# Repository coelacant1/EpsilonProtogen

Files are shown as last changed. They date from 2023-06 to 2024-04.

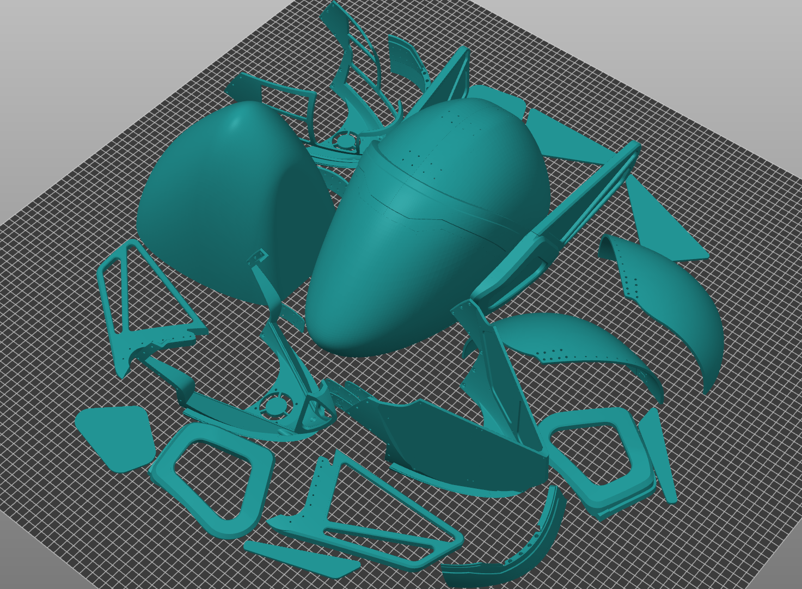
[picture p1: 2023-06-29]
Pictures/FullPlatter.png

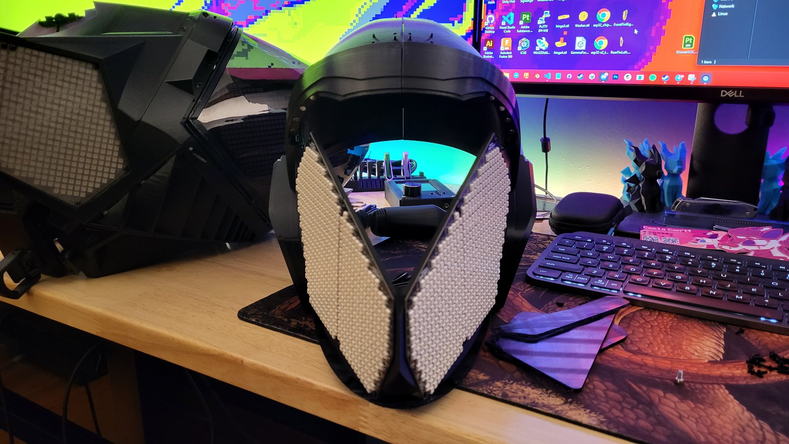
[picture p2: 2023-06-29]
Pictures/1 (4).jpg

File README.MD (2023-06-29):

# Epsilon Protogen

------------------------------------------
Coela Can't! Epsilon Protogen
------------------------------------------

Included are all of the STL files pre-oriented and ready for printing. But what about the visor? Well, two versions of the vacuum forming buck are included as well so you have the ability to make your own PETG visors. Don't forget that the 3D STEP and IGES CAD files are included, so if the design is not exactly what you want then you have the ability to modify and tweak it!

This design is built around printing on the Prusa i3 MK3s with build dimensions of X:250mm, Y:210mm, and Z:210mm. This design can be printed on smaller printers but may need to be modified or split requiring glue or the addition of screw mounts.

------------------------------------------
ASSEMBLY
------------------------------------------
Parts list:
Generic metric hardware kit (M3, M4, M5): https://www.amazon.com/Assortment-AETTL-Stainless-Assorted-Wrenches/dp/B098ND1GW8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
Threaded insert kit (M2, M3, M4, M5): https://www.amazon.com/DYWISHKEY-Knurled-Threaded-Embedment-Assortment/dp/B07MWBJB67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
M2 Screws: https://www.amazon.com/uxcell-M2x6mm-Thread-Button-Socket/dp/B01B1OD9UQ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

The frame will bolt together with the use of M3 hardware, almost entirely with M3x16mm, ensure the screws are not protruding.
The rear LED board mount will be attached using M2 threaded inserts into the frame and M2x6mm screws for the cover and mount.
The top hinge is mounted with M4 threaded inserts and the hinge mechanism uses an M5 threaded insert and an M5x30mm bolt.
The rear latches are mounted with M3 threaded inserts and M3x10mm screws and use M5x8mm bolts with 20mm M5 grub screws.

------------------------------------------
VISOR
------------------------------------------
Print the Buck
Make a vacuum former tutorial: https://www.youtube.com/watch?v=Gx66mS7U2vY
Material: Use 0.06" or 2.0mm PETG for proper thickness 

Magnetic mounts visor mount should be attached with a form of adhesive - double sided tape or epoxy - careful with super glue on the visor though! It will cloud it up. Use 6mmx2mm neodymium magnets and check the direction: https://www.amazon.com/FINDMAG-Refrigerator-Magnets-Premium-Whiteboard/dp/B075RZ82HP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

------------------------------------------
3D Printing
------------------------------------------
Recommended build dimensions: 250mmx210mmx210mm
Resolution: 0.2mm or higher quality
Supports: Not necessary at high resolution, except for jaw.
Brim: Depending on your build surface a brim may be needed to bed adhesion
Material: PETG for frame and PVB for transparent covers - PLA can be used but it can melt if left in hot areas or in vehicles

------------------------------------------
Electronics
------------------------------------------
Controller:
Teensy 4.0: https://www.pjrc.com/store/teensy40.html
OctoWS2811 LED Controller for the Teensy 4.0: https://www.pjrc.com/store/octo28_adaptor.html

Power: 
USB-C Decoy Trigger (USB-C to set voltage out): https://www.amazon.com/Type-C-USB-C-charge-trigger-detector/dp/B07T6LPP9W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
Buck Converter (5v-38V input to 5V output): https://www.amazon.com/Pololu-Step-Down-Voltage-Regulator-D24V90F5/dp/B01M9C9Q1E
Recommend 20W+ USB-C PD battery

Provide 5V directly to the LED boards from the buck converter and the signal lines from the OctoWS2811 controller.

------------------------------------------
Software
------------------------------------------
Software for controlling the head can be found at: https://github.com/coelacant1/ProtoTracer

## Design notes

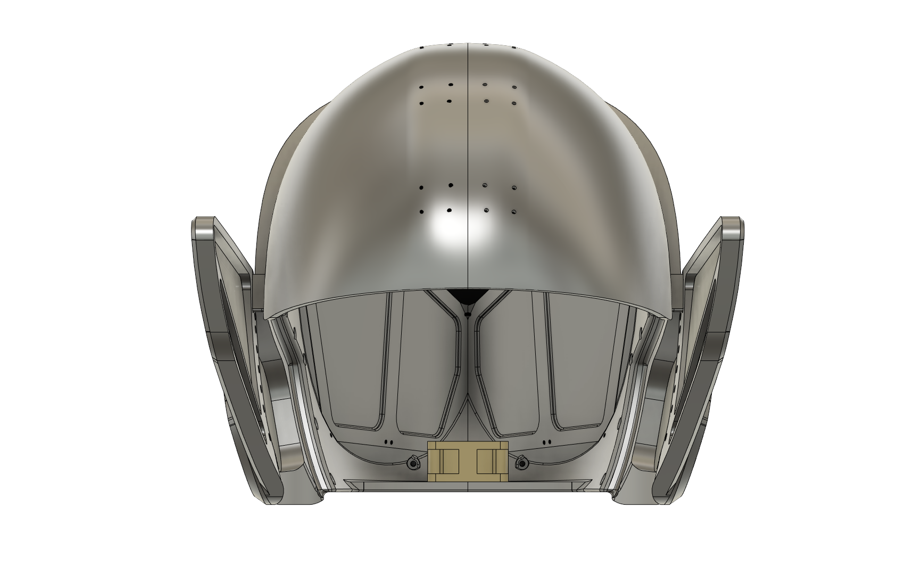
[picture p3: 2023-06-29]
Pictures/Back.png

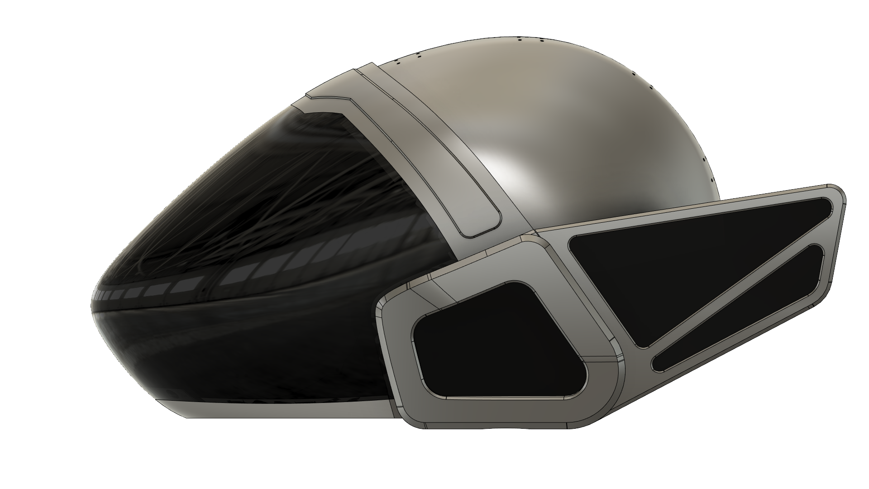
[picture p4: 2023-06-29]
Pictures/Side.png

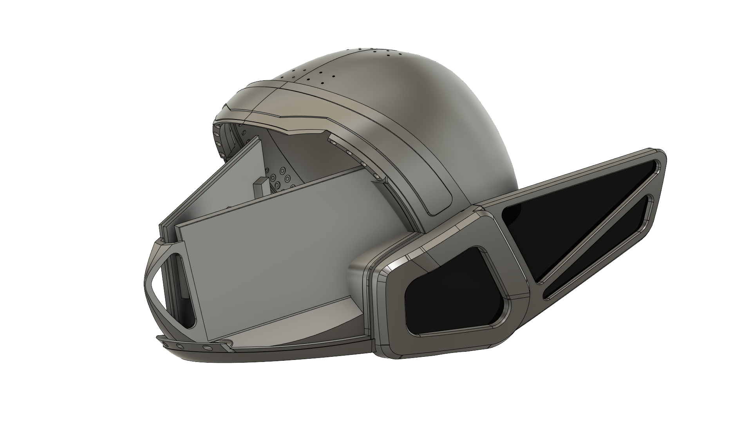
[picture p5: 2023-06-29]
Pictures/HUB75.png

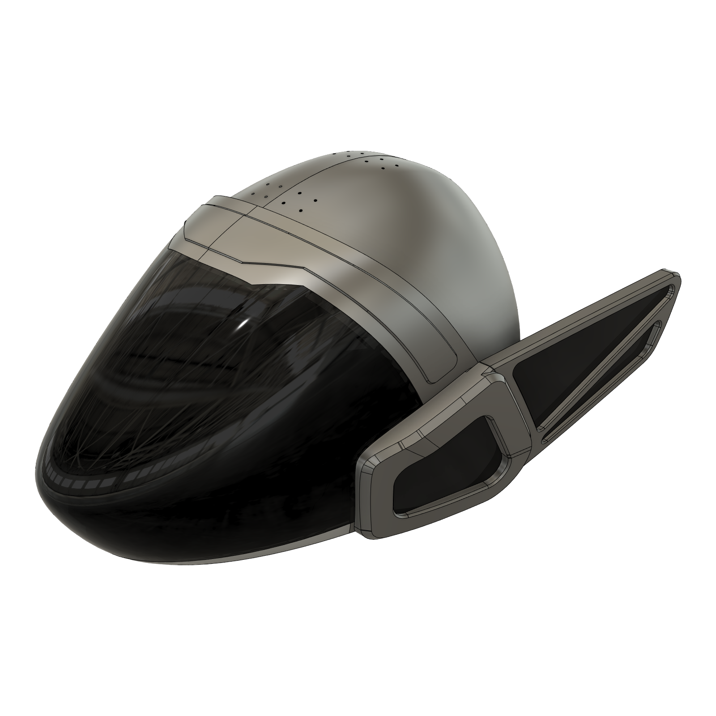
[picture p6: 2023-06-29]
Pictures/Full.png

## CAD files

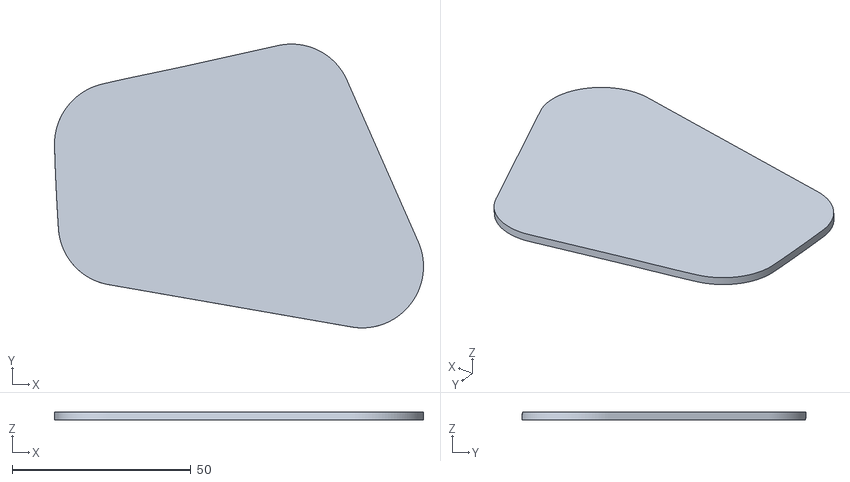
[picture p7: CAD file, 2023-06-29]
Frame/Left/MainFinDisplay.stl
103.1 x 79.3 x 2.19

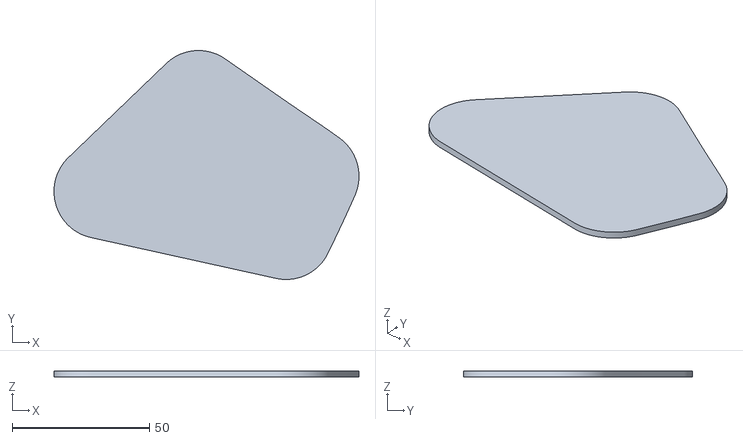
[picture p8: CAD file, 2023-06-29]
Frame/Right/MainFinDisplay.stl
111.0 x 83.3 x 2.19

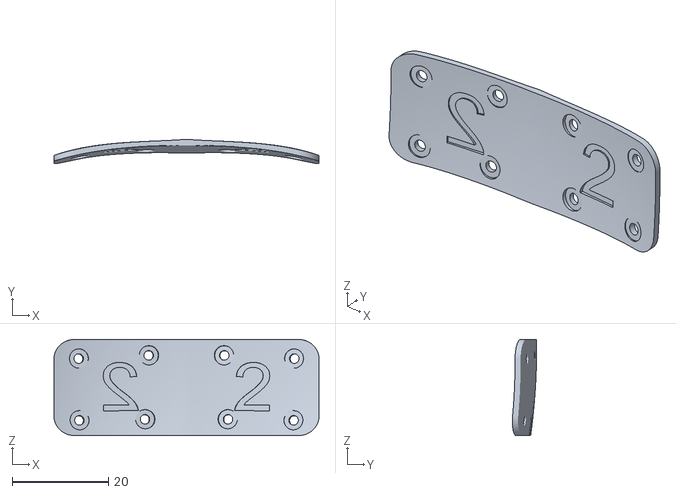
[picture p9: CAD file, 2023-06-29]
Frame Connectors/HelmetJoin2.stl
55.0 x 5.06 x 20.0

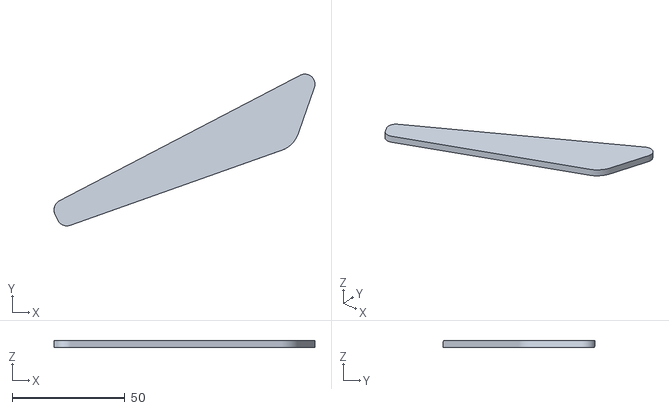
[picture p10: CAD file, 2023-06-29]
Frame/Left/RearBottomFinDisplay.stl
115.9 x 67.4 x 3.29

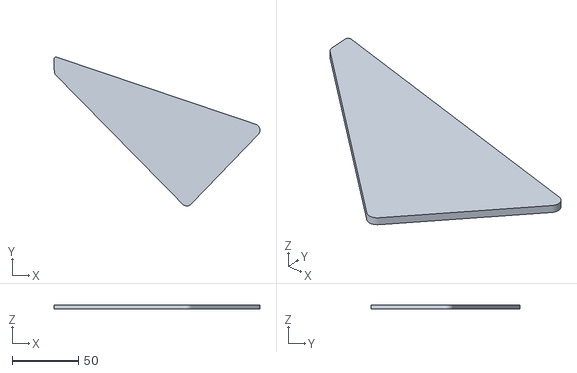
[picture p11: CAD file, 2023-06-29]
Frame/Right/RearTopFinDisplay.stl
155.2 x 112.3 x 3.29

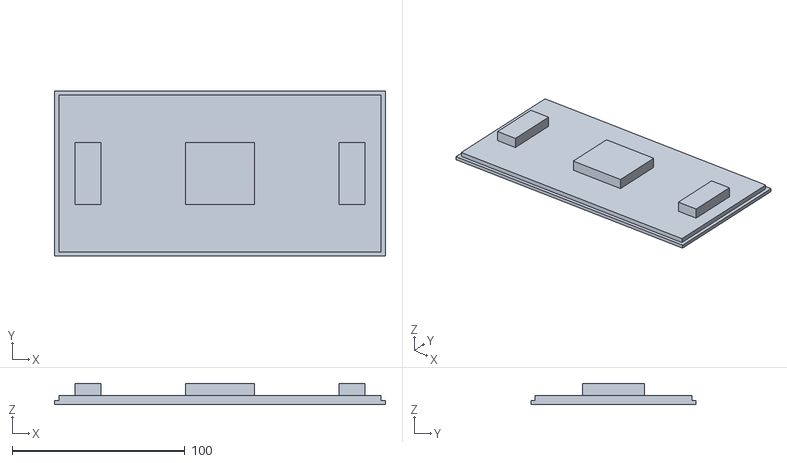
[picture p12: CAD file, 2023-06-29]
HUB75/HUB75PanelReference.stl
191.8 x 95.8 x 12.3

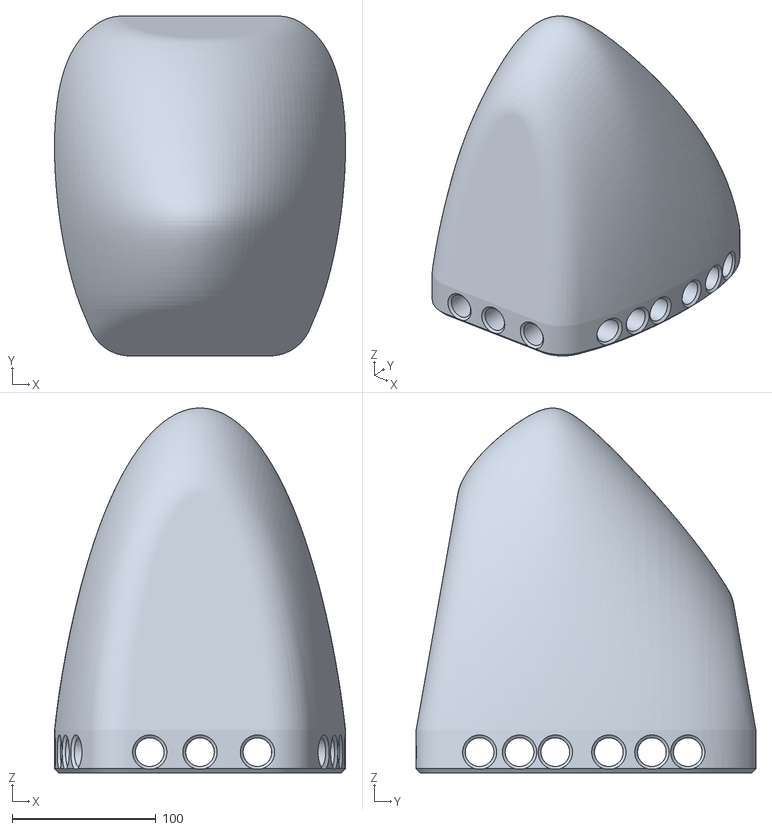
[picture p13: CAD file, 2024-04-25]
Visor/Buck.stl
202.6 x 236.5 x 254.1

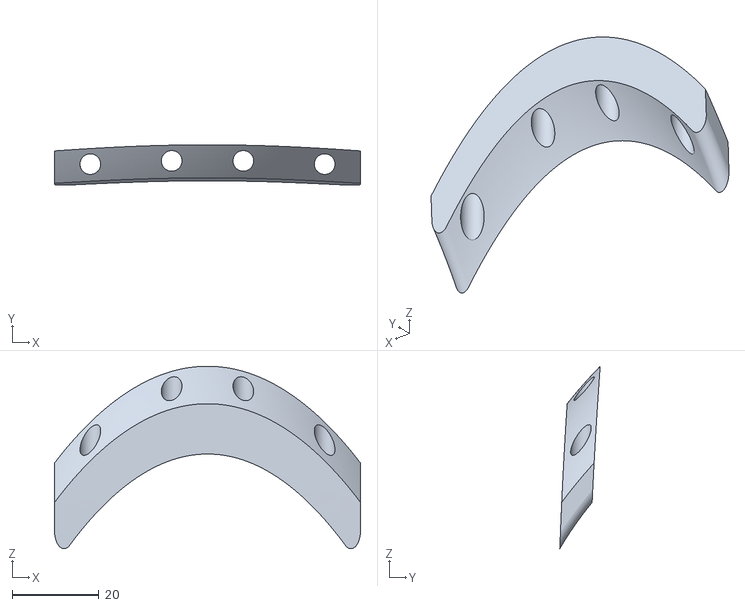
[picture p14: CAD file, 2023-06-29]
Visor/Mount/MagMntChin.stl
70.5 x 9.29 x 42.0

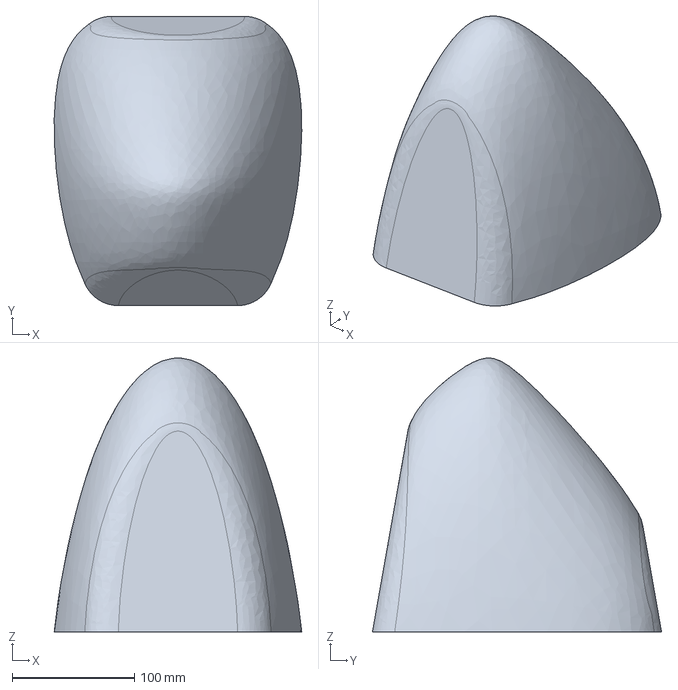
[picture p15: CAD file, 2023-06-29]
VisorBuck.step
202.5 x 236.5 x 224.1 mm

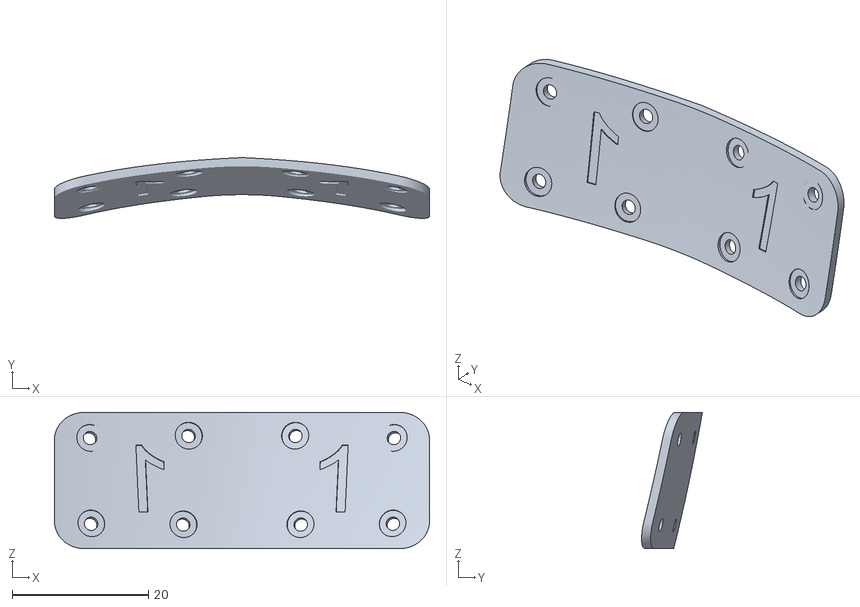
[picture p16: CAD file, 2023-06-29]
Frame Connectors/HelmetJoin1.stl
55.0 x 8.93 x 20.0

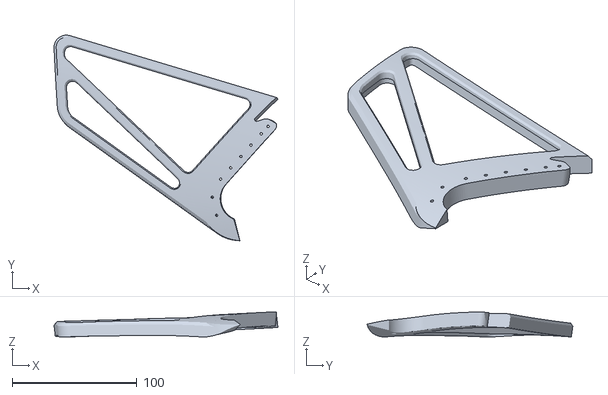
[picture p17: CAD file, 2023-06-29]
Frame/Right/RearFinRight.stl
179.5 x 164.9 x 20.0

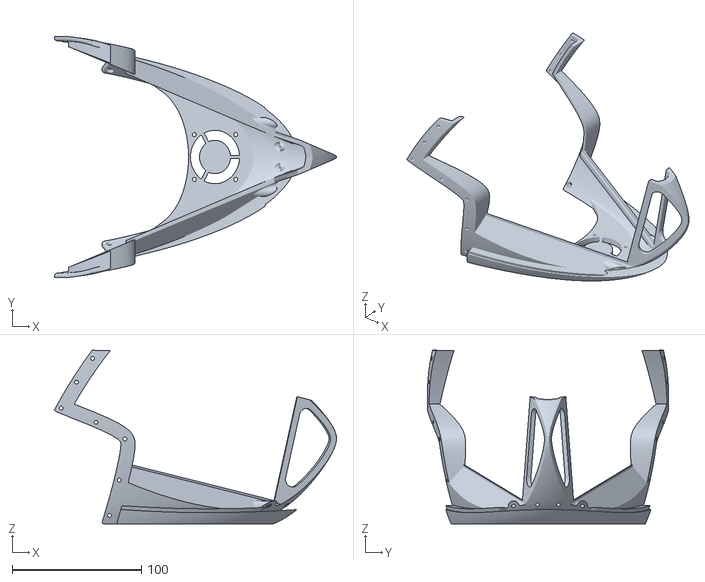
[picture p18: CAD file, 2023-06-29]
HUB75/HUB75Face.stl
217.9 x 186.5 x 134.1

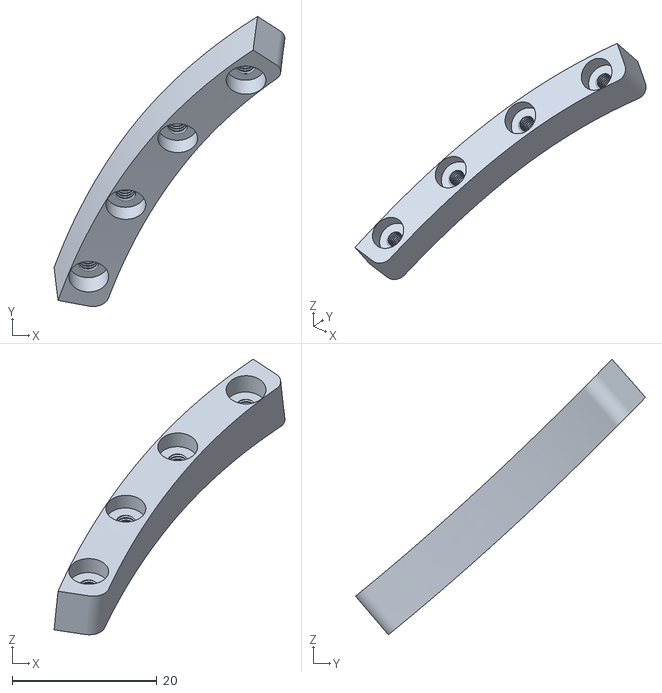
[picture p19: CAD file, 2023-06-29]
Visor/Mount/ForeheadTopRight.stl
31.9 x 40.1 x 38.1

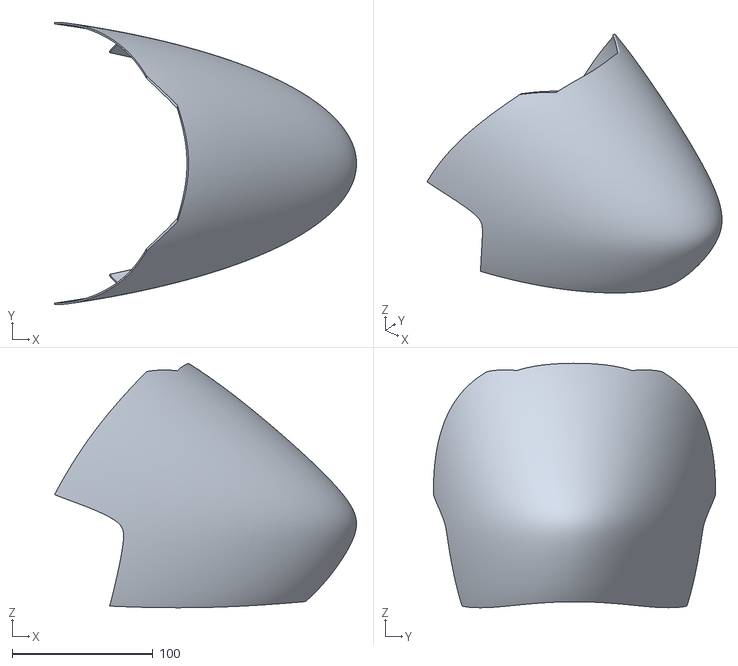
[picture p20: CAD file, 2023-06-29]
Visor/Visor.stl
214.5 x 200.5 x 173.7

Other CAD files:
Frame Connectors/FrontHelmetJoin.stl
Frame/Left/RearTopFinDisplay.stl
Visor/Mount/ForeheadTopLeft.stl
Frame Connectors/HelmetJoin3.stl
Frame Connectors/HelmetJoin4.stl
Frame/Left/RearFinLeft.stl
Frame/Right/RearBottomFinDisplay.stl

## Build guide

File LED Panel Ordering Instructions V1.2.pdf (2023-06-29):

V1.1.2022 - Coela Can’t!

## Coela Can’t!

# Manufacturing Files:

## Protogen LED Board V1

Page 2 of 17

## Contents

## 0 Overview

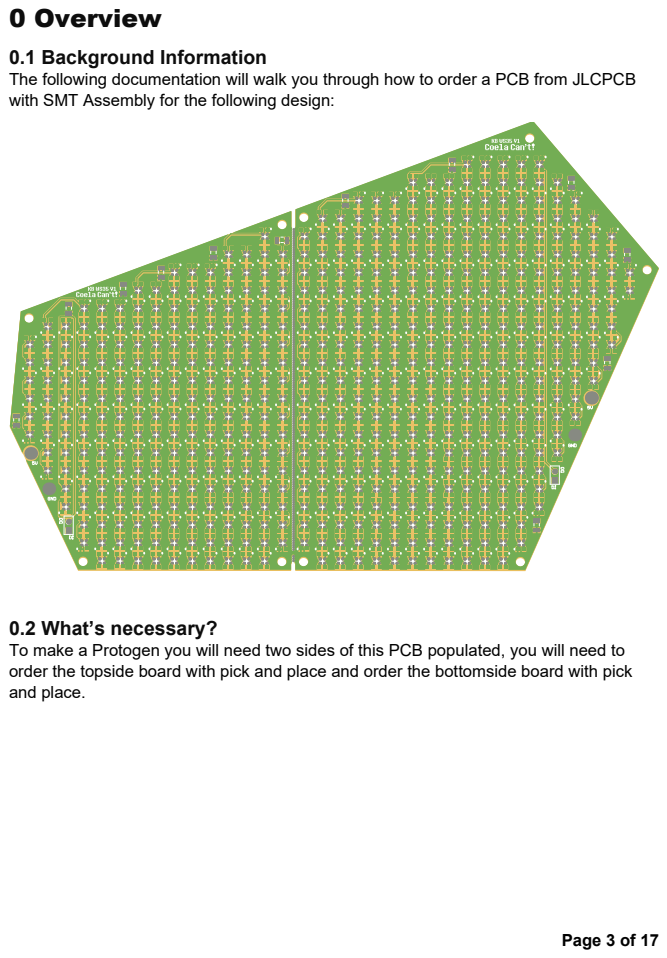
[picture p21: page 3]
Page 3 of 17

0.1 Background Information
The following documentation will walk you through how to order a PCB from JLCPCB
with SMT Assembly for the following design:

0.2 What’s necessary?
To make a Protogen you will need two sides of this PCB populated, you will need to
order the topside board with pick and place and order the bottomside board with pick
and place.

## 1 Ordering the LED Panels

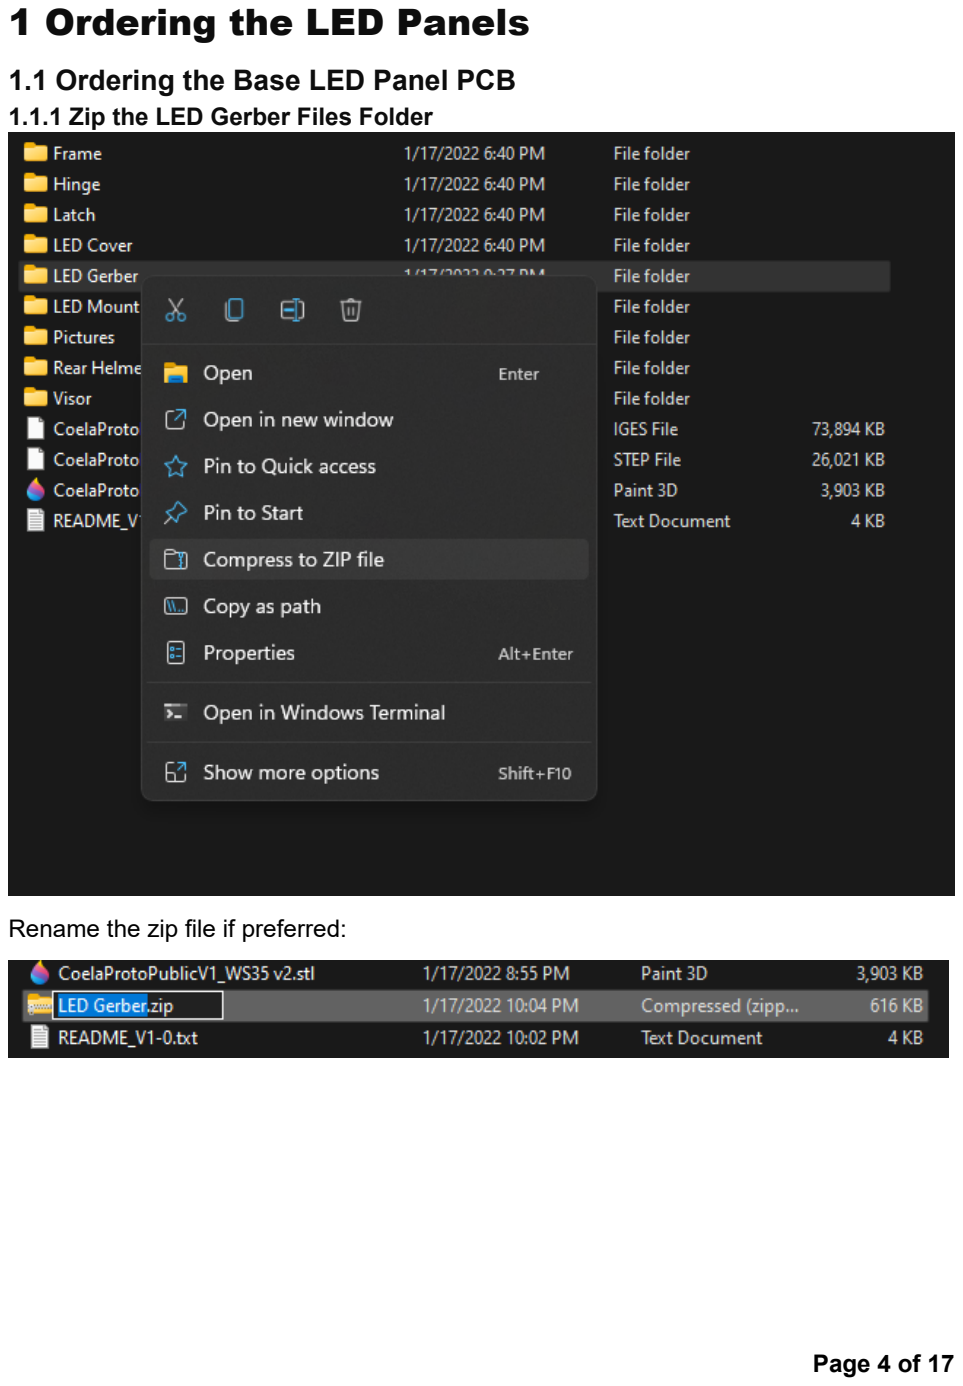
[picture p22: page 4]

Page 4 of 17

### 1.1 Ordering the Base LED Panel PCB

### 1.1.1 Zip the LED Gerber Files Folder

Rename the zip file if preferred:

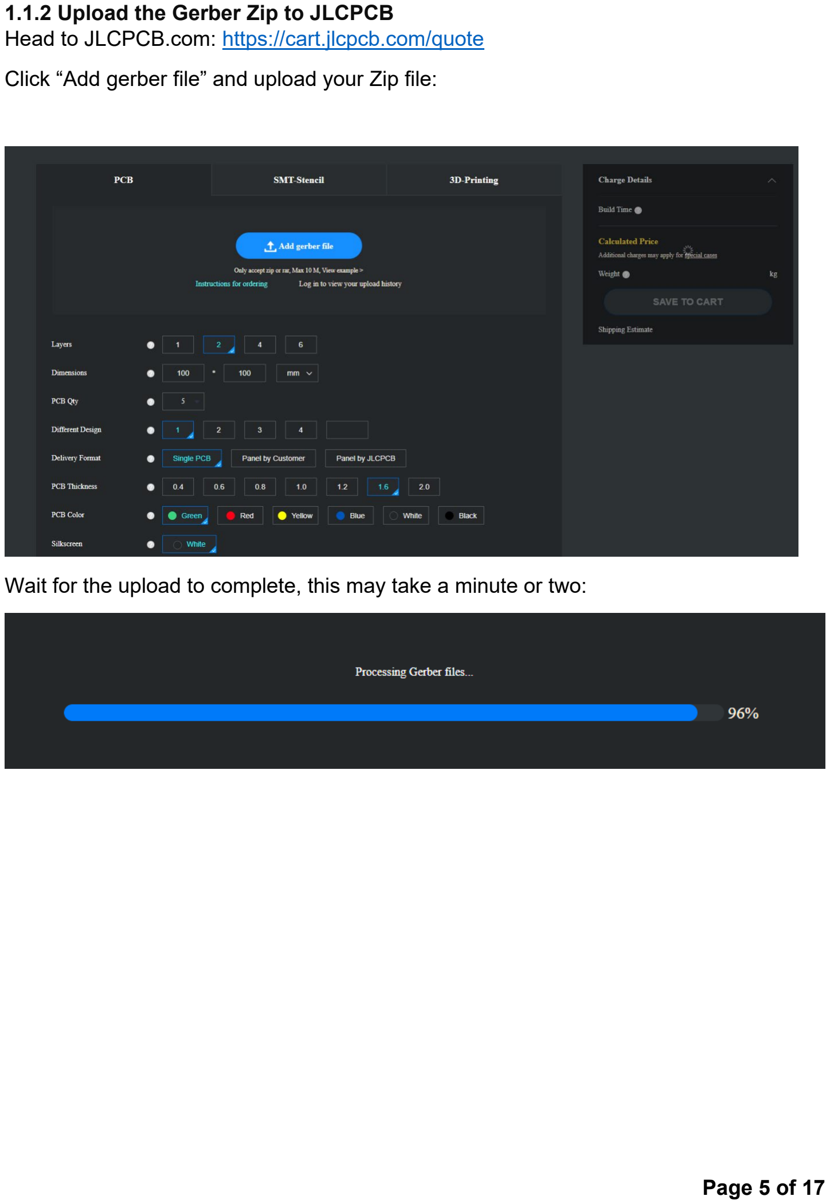
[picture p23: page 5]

Page 5 of 17

### 1.1.2 Upload the Gerber Zip to JLCPCB

Head to JLCPCB.com: https://cart.jlcpcb.com/quote Click “Add gerber file” and upload your Zip file:

Wait for the upload to complete, this may take a minute or two:

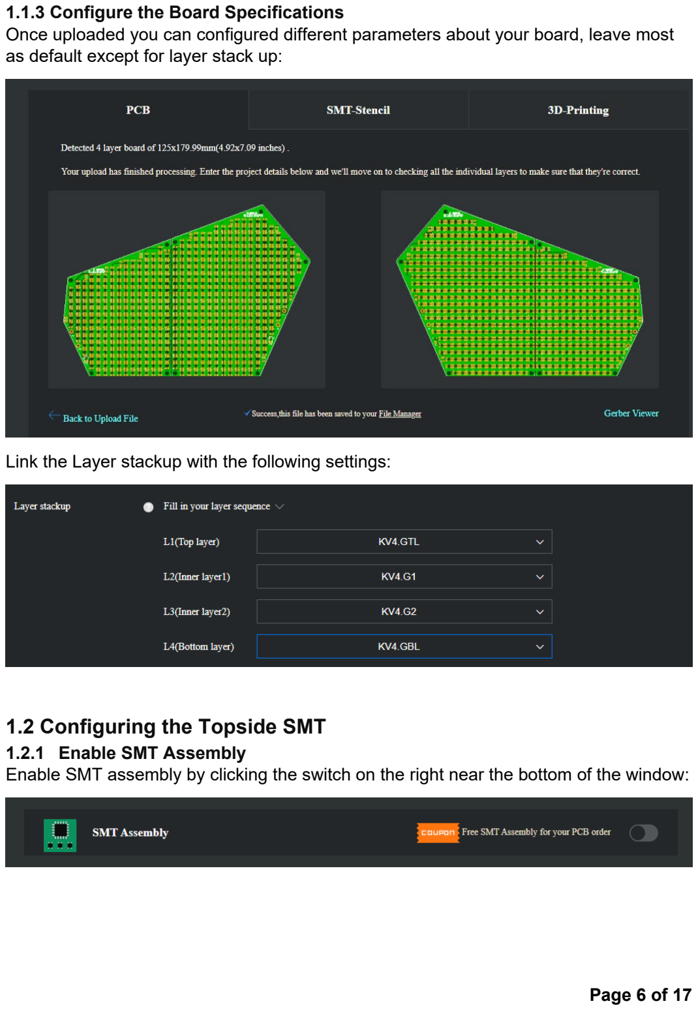
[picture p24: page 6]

Page 6 of 17

### 1.1.3 Configure the Board Specifications

Once uploaded you can configured different parameters about your board, leave most as default except for layer stack up:

Link the Layer stackup with the following settings:

### 1.2 Configuring the Topside SMT

### 1.2.1 Enable SMT Assembly

Enable SMT assembly by clicking the switch on the right near the bottom of the window:

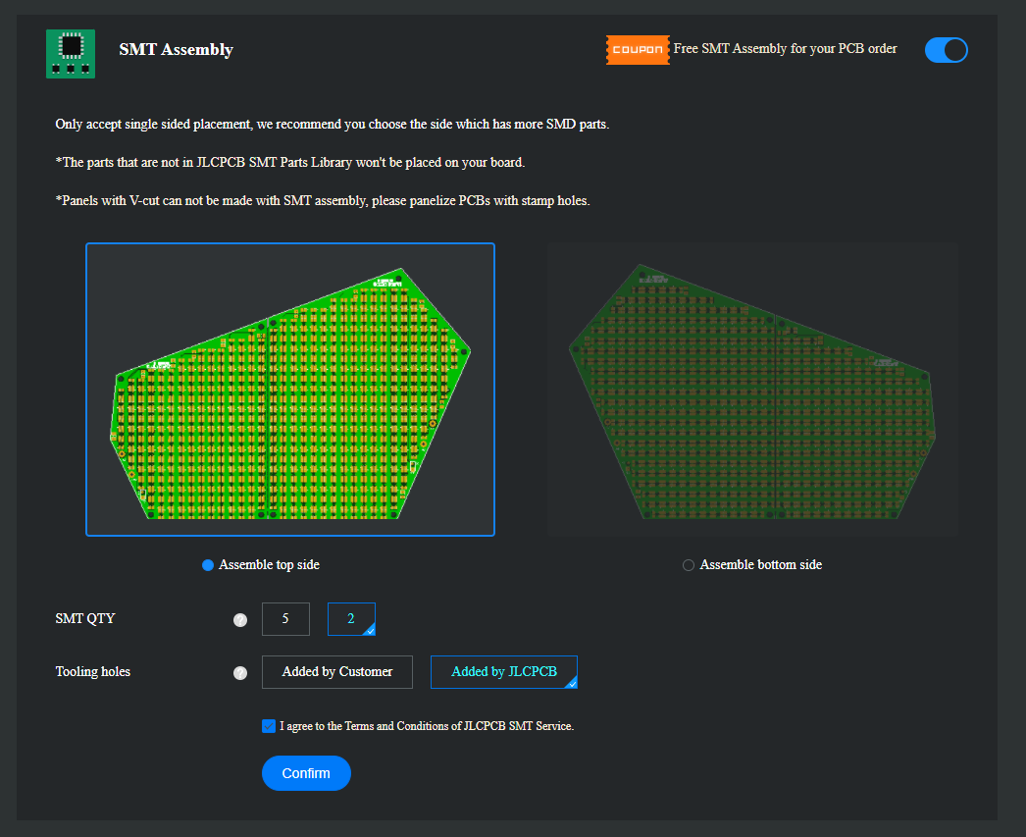
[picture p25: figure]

Page 7 of 17

Select the quantity of LED boards you would like assembled, 2 or 5. For more you will need to order one board first, test it, and then repurchase from the site with your confirmed files:

Click confirm to continue to the rest of the process.

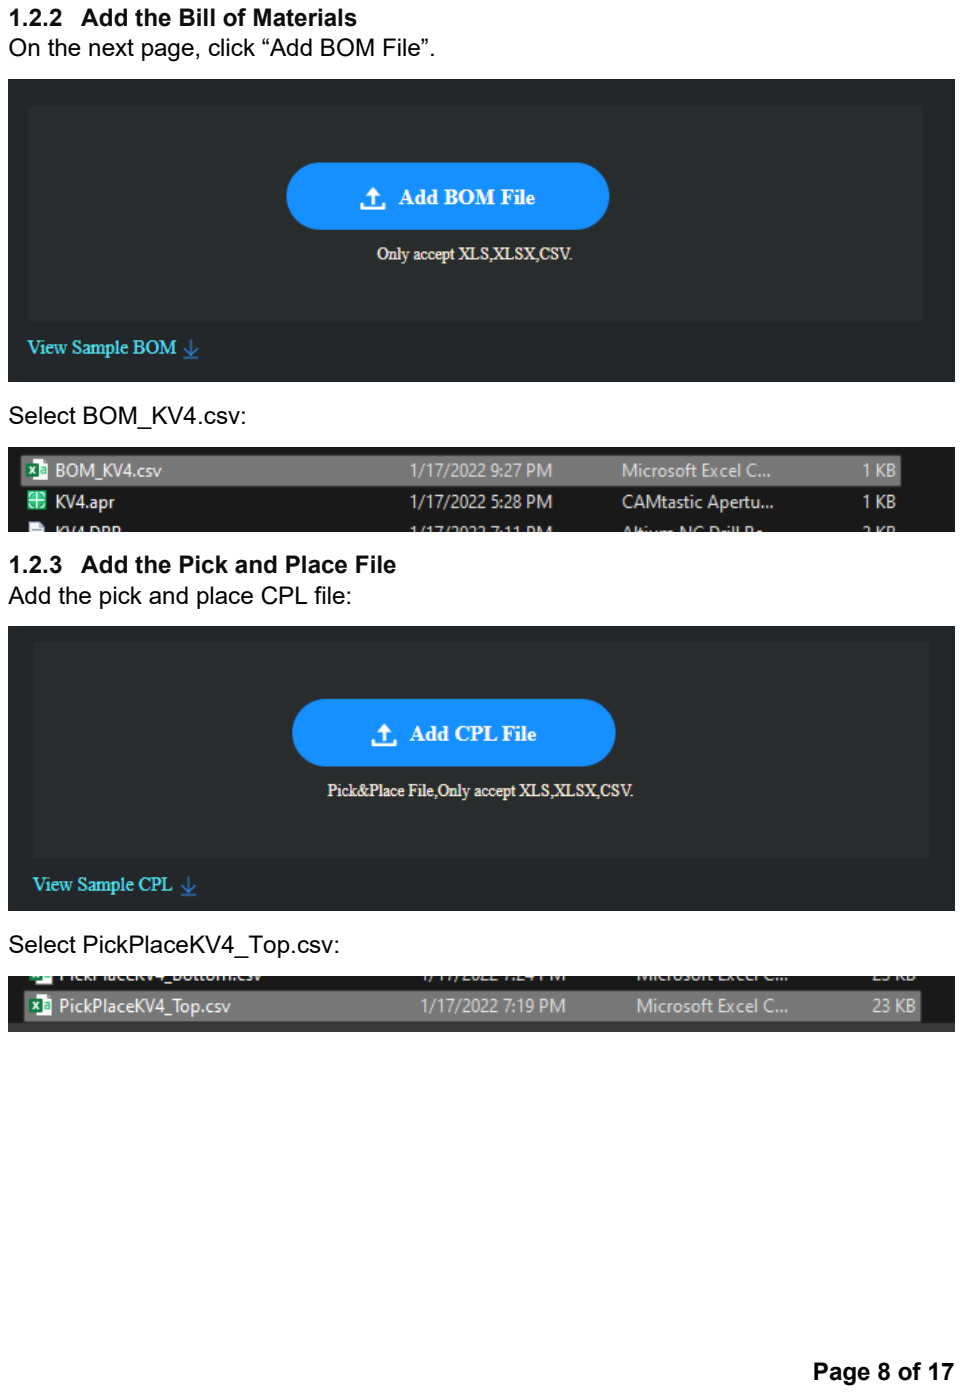
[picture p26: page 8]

Page 8 of 17

### 1.2.2 Add the Bill of Materials

On the next page, click “Add BOM File”.

Select BOM_KV4.csv:

### 1.2.3 Add the Pick and Place File

Add the pick and place CPL file:

Select PickPlaceKV4_Top.csv:

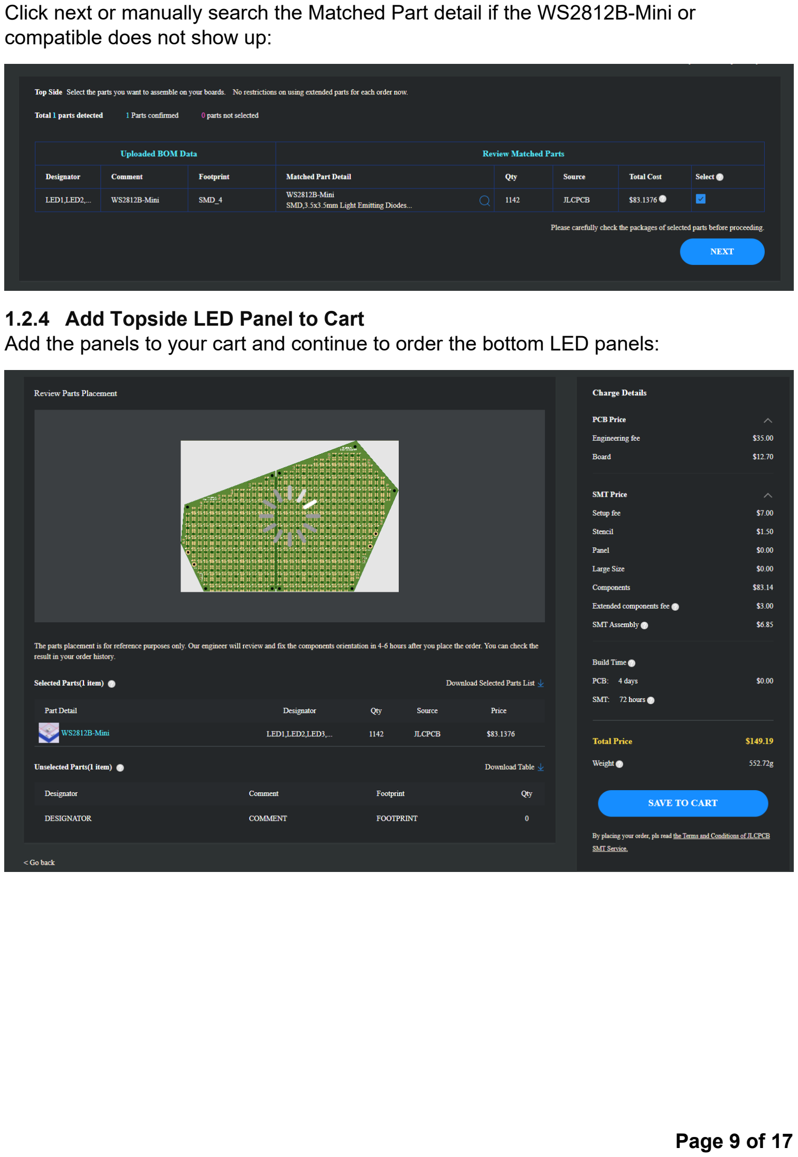
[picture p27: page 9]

Page 9 of 17

Click next or manually search the Matched Part detail if the WS2812B-Mini or compatible does not show up:

### 1.2.4 Add Topside LED Panel to Cart

Add the panels to your cart and continue to order the bottom LED panels:

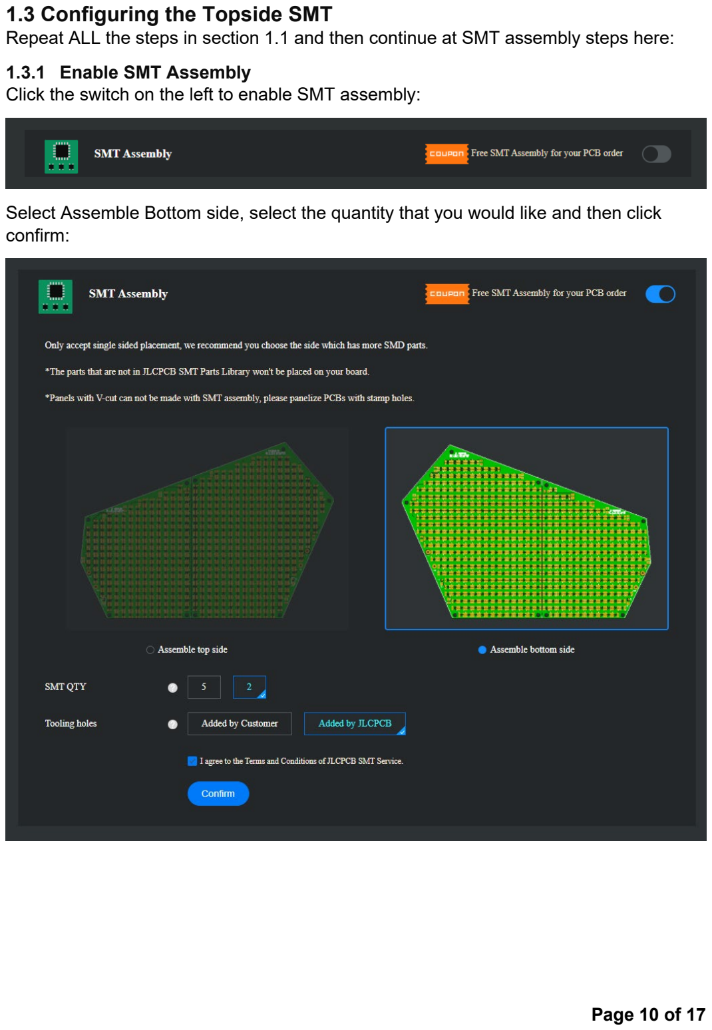
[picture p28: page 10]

Page 10 of 17

### 1.3 Configuring the Topside SMT

Repeat ALL the steps in section 1.1 and then continue at SMT assembly steps here:

### 1.3.1 Enable SMT Assembly

Click the switch on the left to enable SMT assembly:

Select Assemble Bottom side, select the quantity that you would like and then click confirm:

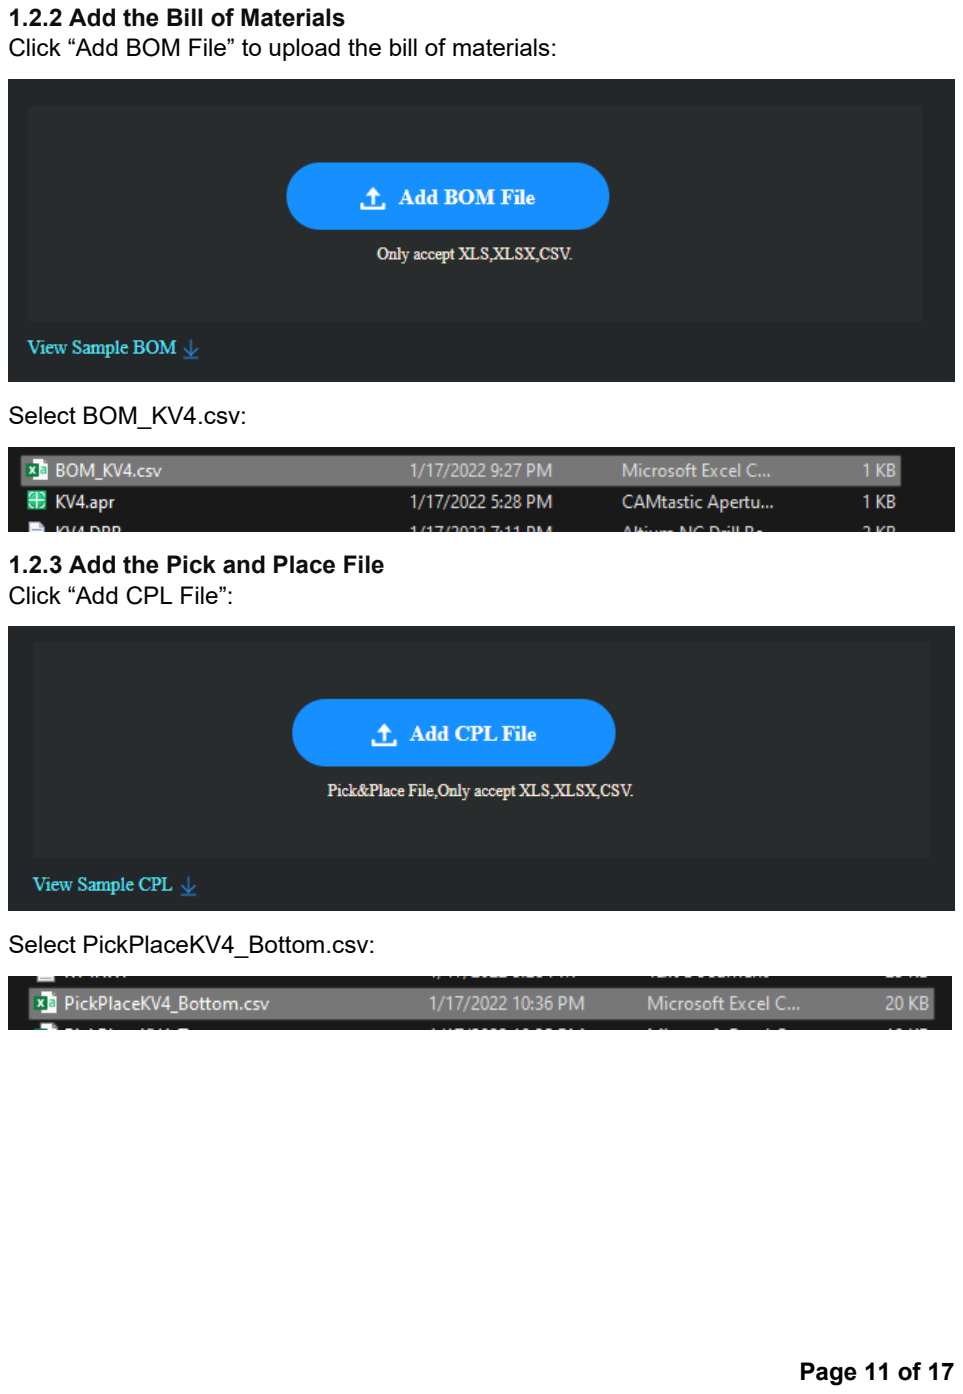
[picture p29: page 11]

Page 11 of 17

### 1.2.2 Add the Bill of Materials

Click “Add BOM File” to upload the bill of materials:

Select BOM_KV4.csv:

### 1.2.3 Add the Pick and Place File

Click “Add CPL File”:

Select PickPlaceKV4_Bottom.csv:

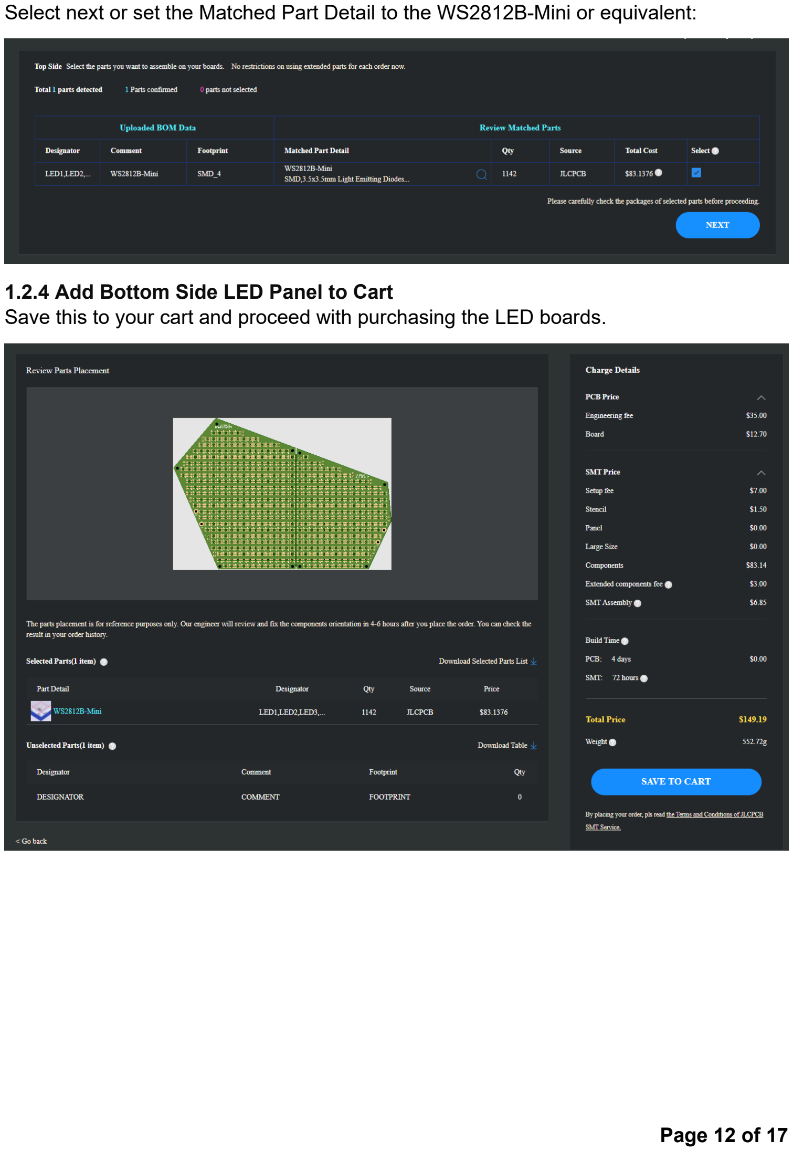
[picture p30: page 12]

Page 12 of 17

Select next or set the Matched Part Detail to the WS2812B-Mini or equivalent:

### 1.2.4 Add Bottom Side LED Panel to Cart

Save this to your cart and proceed with purchasing the LED boards.

Page 13 of 17

## 2 Using the LED Panels

These LED boards use WS2812B-Mini serialized LEDs, these are glorified LED strips and can be controlled with the same controller! Each board has 571 LEDs which need to be controlled. This can be done through several means; I would recommend using my ProtoTracer program which will ray trace a live 3D model of a Protogen face to the LED panel in real time! You can find this here: https://github.com/coelacant1/ProtoTracer

An alternative is to use FastLED with Arduino and manually define the pixels in order.

The hardware necessary to controller the panels is a Teensy 4.0 microcontroller: https://www.pjrc.com/store/teensy40.html and an OctoWS2811 (https://www.pjrc.com/store/teensy40.html%20and%20an%20OctoWS2811) LED controller: https://www.pjrc.com/store/octo28_adaptor.html

To use this, include the ProtoV2Controller.h as the primary controller and pick the animation to display on the face from the animations class. Use the KaiborgV1 animation as a default Protogen face.

To increase the framerate the boards can be split in two with the perforation in the middle.

# TOP VIEW

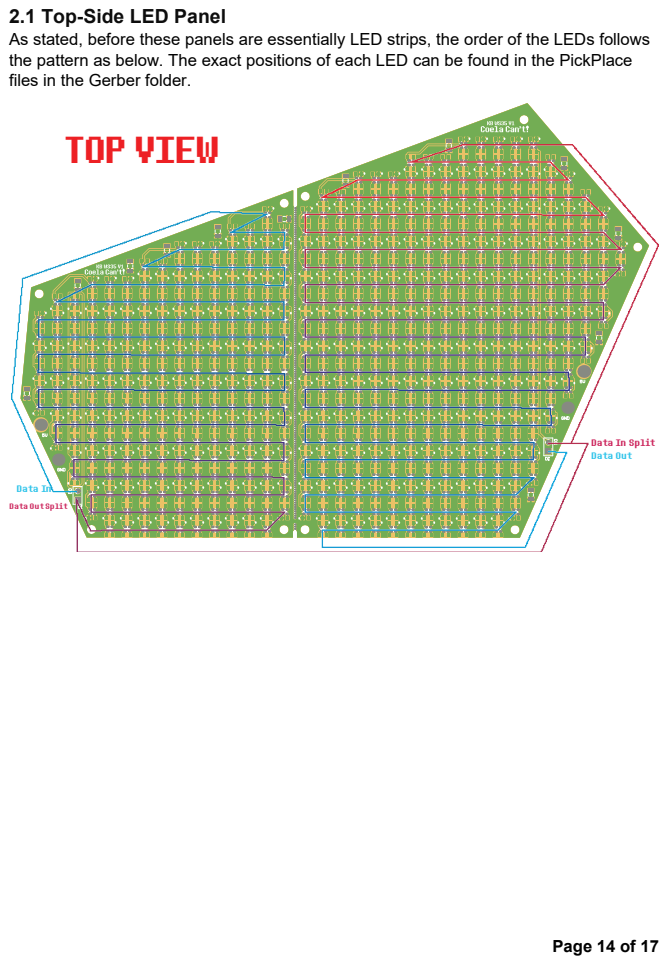
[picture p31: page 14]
Page 14 of 17

2.1 Top-Side LED Panel
As stated, before these panels are essentially LED strips, the order of the LEDs follows
the pattern as below. The exact positions of each LED can be found in the PickPlace
files in the Gerber folder.

Data In Split
Data Out

Data In
Data Out Split

# Bottom VIEW

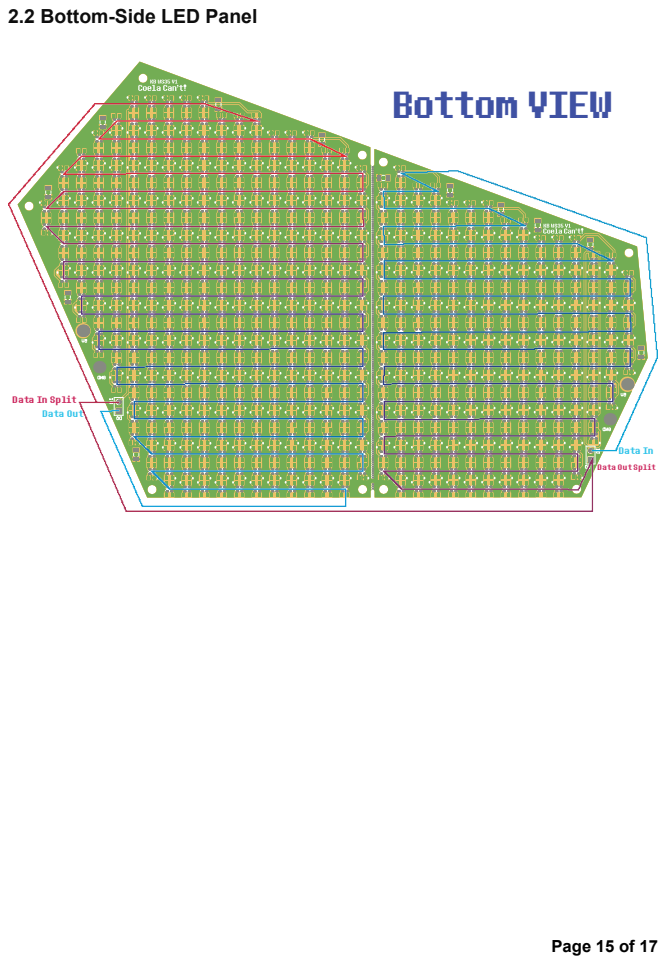
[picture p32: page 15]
Page 15 of 17

2.2 Bottom-Side LED Panel

Data In Split
Data Out

Data In
Data Out Split

## 3 Troubleshooting

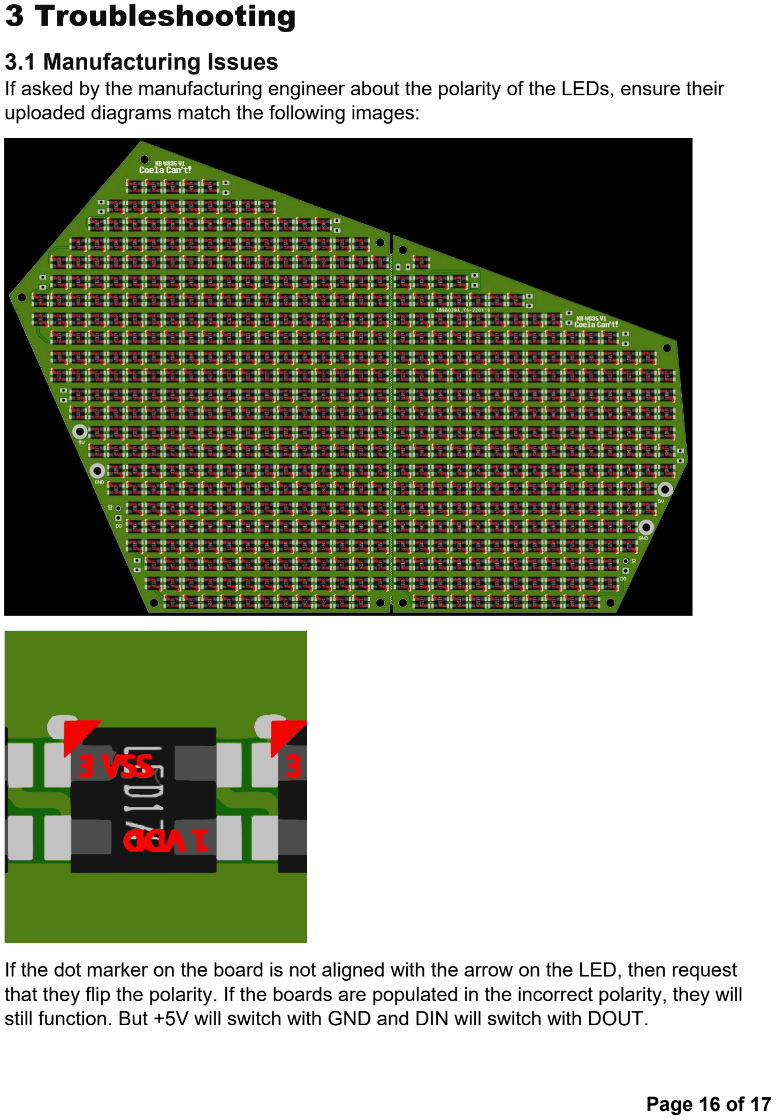
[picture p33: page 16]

Page 16 of 17

### 3.1 Manufacturing Issues

If asked by the manufacturing engineer about the polarity of the LEDs, ensure their uploaded diagrams match the following images:

If the dot marker on the board is not aligned with the arrow on the LED, then request that they flip the polarity. If the boards are populated in the incorrect polarity, they will still function. But +5V will switch with GND and DIN will switch with DOUT.

Page 17 of 17

## 4 Contact Information

If you have any questions that this document did not answer, or have recommendations please let me know at any of my messaging platforms here: https://linktr.ee/coelacant1 For easiest and quickest responses, use Telegram: @coelacant1, Twitter: @coelacant1, or Discord: @Coelacanth#1250

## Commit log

2023-06-29 Initial upload
    [Buck.stl, ForeheadTopLeft.stl, ForeheadTopRight.stl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]
2024-04-25 Improved Buck Design
    Improved buck design, created by @ATunaCan
    [Buck.stl]
